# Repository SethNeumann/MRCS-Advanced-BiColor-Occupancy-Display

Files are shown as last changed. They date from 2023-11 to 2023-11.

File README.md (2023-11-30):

# REPO NAME:     MRCS-Advanced-BiColor-Occupancy-Display

## License: Creative Commons Attribution-NonCommercial-ShareAlike

The original board, which I designed for Allison Dendy had a pull up SIP (4.7K) and second SIP (nominally 470 ohms) on the common anode to limit
current. Depending on the 3 lead Red/Green LED used the Red was significantly brighter than the Green. Green/Red brightness is always an issue as 
about 20% of males have some red/green color weakness, so adjustment is very individual.

This version has an additional DIP resistor pack in series with the Red leads to further limit the Red brigtness. I used A 220 ohm SIP for the common
anode and 1K for the red. This made the Jameco 2266591 LED appear about as bright on each side to me.

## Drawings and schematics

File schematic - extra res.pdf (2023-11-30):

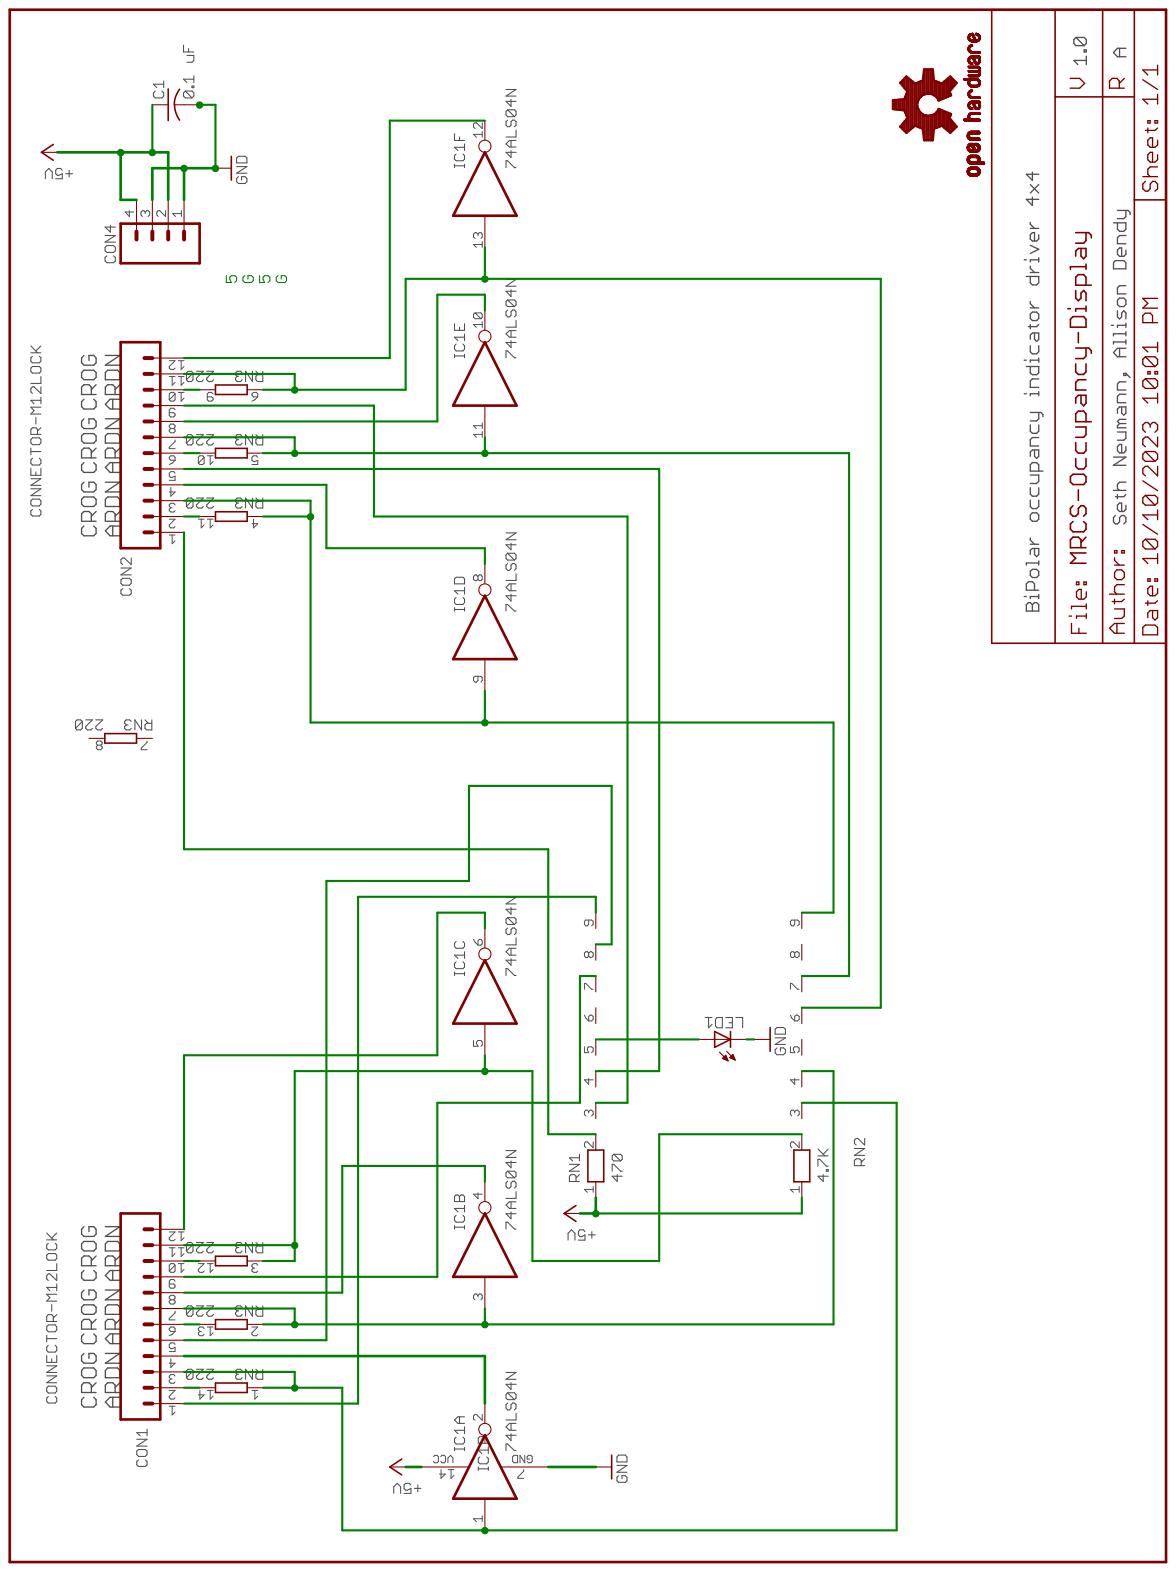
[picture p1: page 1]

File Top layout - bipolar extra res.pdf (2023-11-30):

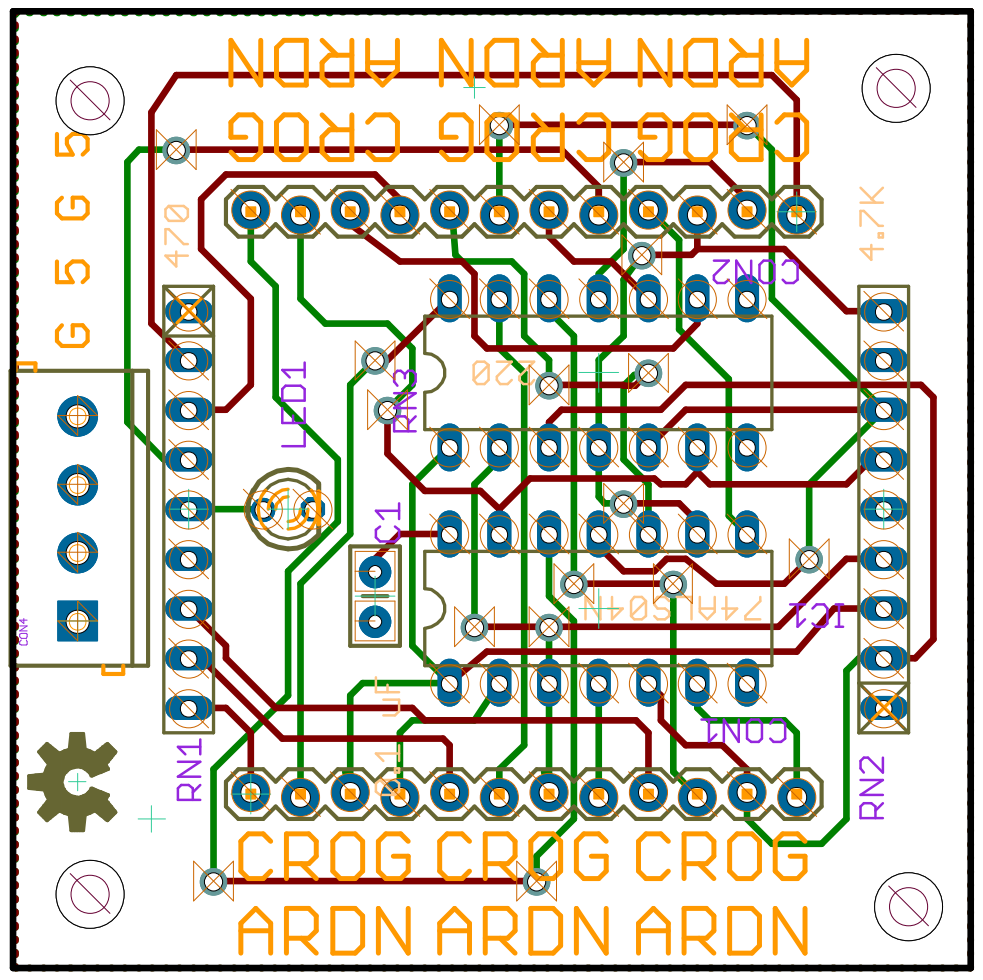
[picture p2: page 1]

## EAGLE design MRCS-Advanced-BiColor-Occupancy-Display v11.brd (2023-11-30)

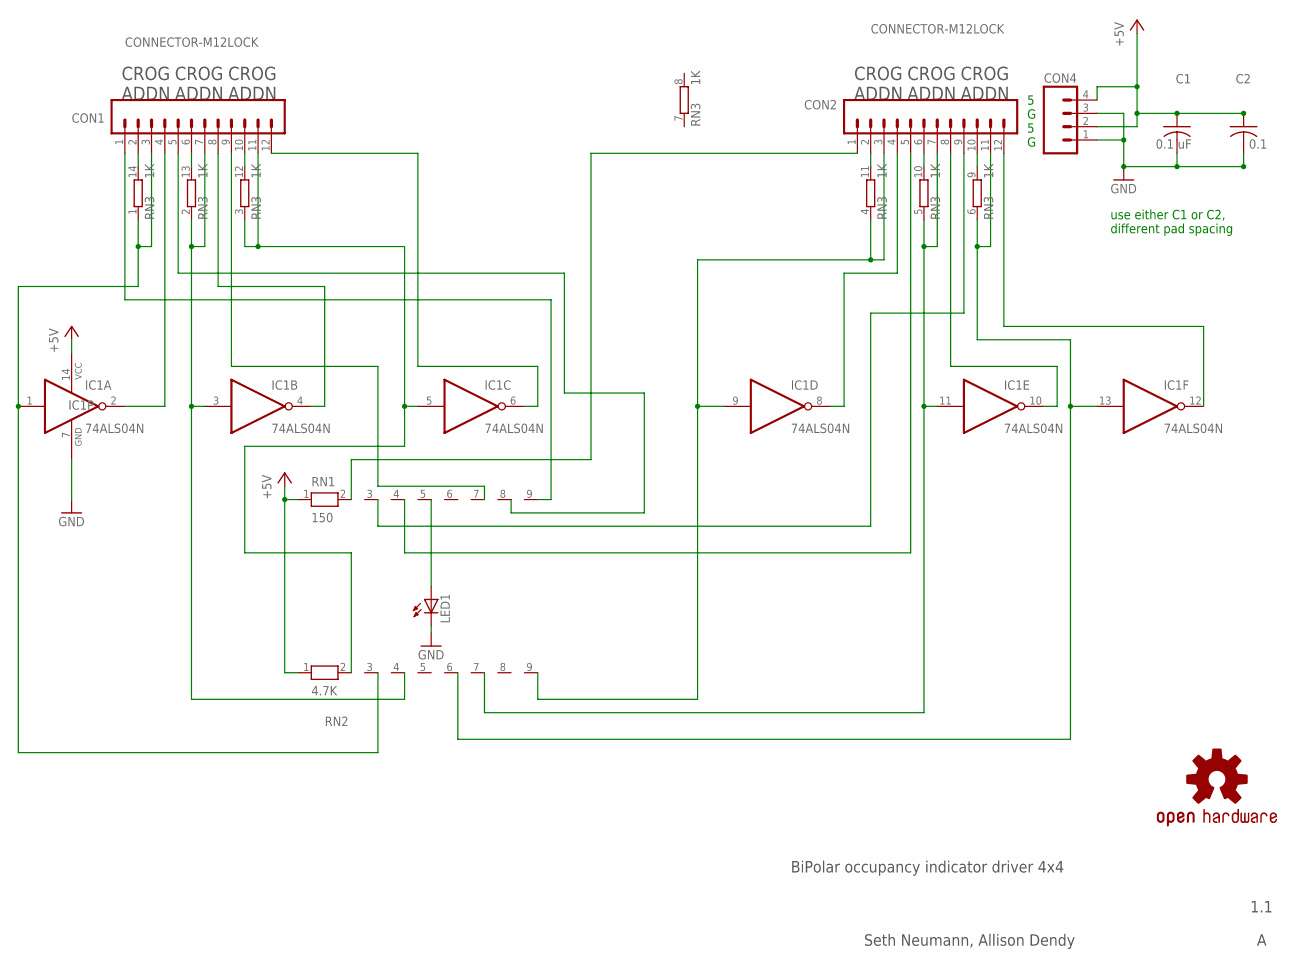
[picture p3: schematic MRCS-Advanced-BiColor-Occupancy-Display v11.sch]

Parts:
C1: 0.1 uF; C-PTH-0.100
C2: 0.1; C050-024X044
CON1, CON2: CONNECTOR-M12LOCK; 1X12_LOCK
CON4: CONNECTOR-M04SCREW; SCREWTERMINAL-3.5MM-4
IC1: 74ALS04N; DIL14
LED1: LEDLED3MM; LED3MM
OSHW1: DOC-OSHW-LOGO-M; OSHW-LOGO-M
RN1: 150; RN-9
RN2: 4.7K; RN-9
RN3: 1K; DIL14

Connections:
GND: C1.2, C2.2, CON4.1, CON4.3, IC1.7 (GND), LED1.K (C)
unnamed: CON1.2, RN3.14 (2)
unnamed: CON1.11, IC1.5 (I), RN2.2, RN3.3 (1)
unnamed: CON1.1, RN1.9
unnamed: CON1.4, IC1.2 (O)
unnamed: CON1.7, IC1.3 (I), RN2.4, RN3.2 (1)
unnamed: CON1.12, IC1.6 (O)
unnamed: CON1.8, IC1.4 (O)
unnamed: CON1.5, RN1.8
unnamed: CON2.3, IC1.9 (I), RN2.9, RN3.4 (1)
unnamed: CON1.9, RN1.7
unnamed: CON2.8, IC1.10 (O)
unnamed: CON2.12, IC1.12 (O)
unnamed: CON2.4, IC1.8 (O)
unnamed: CON2.1, RN1.2
unnamed: CON2.5, RN1.4
unnamed: CON1.3, IC1.1 (I), RN2.3, RN3.1
unnamed: LED1.A, RN1.5
unnamed: CON2.7, IC1.11 (I), RN2.7, RN3.5 (1)
unnamed: CON2.9, RN1.3
unnamed: CON2.11, IC1.13 (I), RN2.6, RN3.6 (1)
unnamed: CON1.6, RN3.13 (2)
unnamed: CON1.10, RN3.12 (2)
unnamed: CON2.2, RN3.11 (2)
unnamed: CON2.6, RN3.10 (2)
unnamed: CON2.10, RN3.9 (2)
VCC: C1.1, C2.1, CON4.2, CON4.4, IC1.14 (VCC), RN1.1, RN2.1

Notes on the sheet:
BiPolar occupancy indicator driver 4x4
1.1
Seth Neumann, Allison Dendy
CROG ADDN
5 G 5 G
use either C1 or C2, different pad spacing

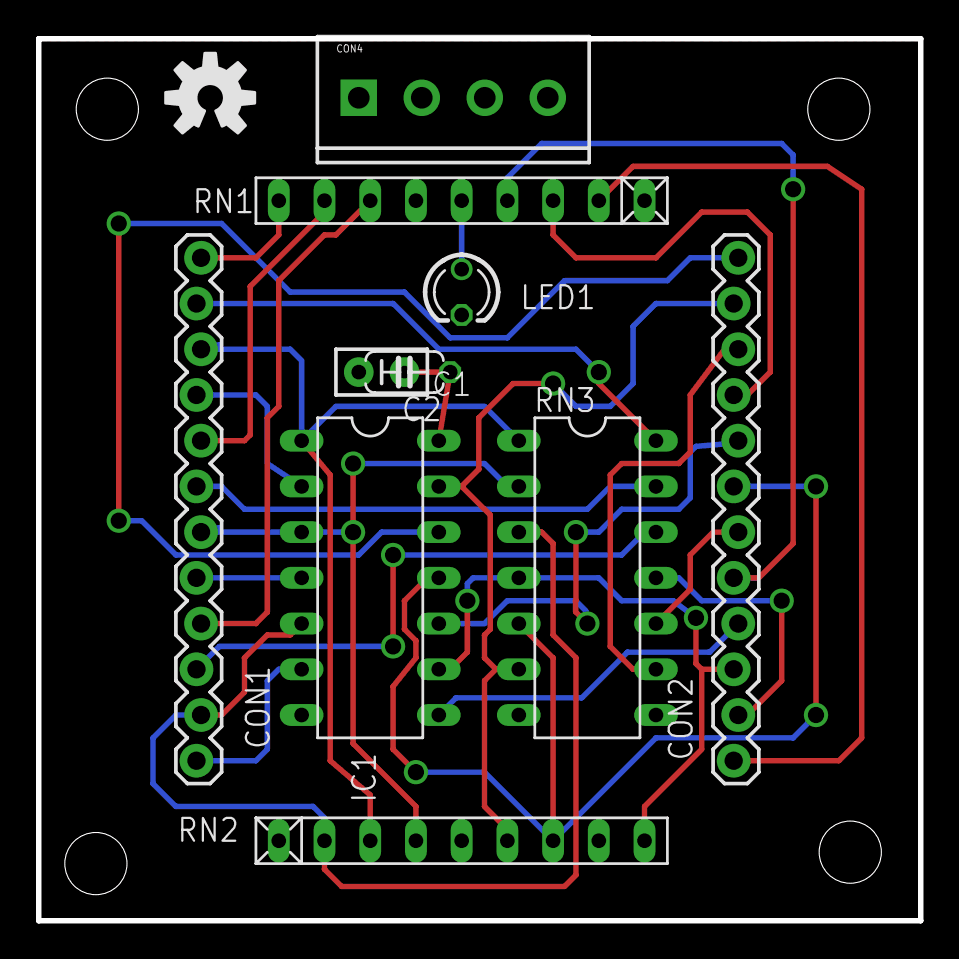
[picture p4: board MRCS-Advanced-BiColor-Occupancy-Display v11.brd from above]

Board: 2 copper layers, 49.0 x 49.0 mm, 13 parts (0 on the bottom side), 27 nets.

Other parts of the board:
U$1: CA-PROP65WARNING
U$2: MRCSLOGOBTM

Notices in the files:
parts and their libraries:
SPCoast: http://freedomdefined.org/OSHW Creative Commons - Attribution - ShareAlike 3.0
